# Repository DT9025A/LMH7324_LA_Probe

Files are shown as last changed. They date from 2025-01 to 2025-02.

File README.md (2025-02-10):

# LMH7324_LA_Probe

使用 KiCad 进行设计的，基于 LMH7324 的 RIGOL PLA2216 逻分探头替代，在 DHO924S 上、62.5MHz 输入频率下实测可用。



# 复刻指导

1. 请依据开源工程 [MSO5000/DHO900 逻辑探头](https://oshwhub.com/zoomf1/pla2216) 中的 "转接板新版本" 打样出转接板，并购买连接器；
2. 依据本工程中的 Gerber 文件打样出探头板，请勿直接使用立创 EDA 进行导出，以免出现意外的错误（即使打 1.6mm 板厚也可以大力出奇迹焊上 1.27mm 的 IDC 连接器）；
3. 购买元器件，LMH7324 在立创商城上约 80RMB / 片；
4. 进行焊接装配。

# 主要 BOM 清单

| 值 | 封装 | 数量 | 
| :---: | :---: | :---: |
| 3.3pF | 0402 | 16 |
| 27pF | 0402 | 16 |
| 100nF | 0402 | 64 |
| 499R | 0402 | 16 |
| 300R | 0402 | 16 |
| 90.9K | 0402 | 16 |
| 10K | 0402 | 16 |
| 49R9 | 4x0603 | 8 |
| 220R | 4x0603 | 8 |
| LMH7324 | WQFN-32-1EP_5x5mm_P0.5mm_EP3.1x3.1mm | 4 |

# Test pictures

校准截图：

校准截图

62.5MHz 方波输入测试：



50MHz 正弦波输入测试：

50MHz正弦波输入测试

# References

- 感谢开源工程 [MSO5000/DHO900 逻辑探头](https://oshwhub.com/zoomf1/pla2216)
- 感谢 [EEVBlog](https://www.eevblog.com/forum/testgear/rpl1116-active-logic-probe-pod-for-1000z-series-teardown/) 中分享资料的各位

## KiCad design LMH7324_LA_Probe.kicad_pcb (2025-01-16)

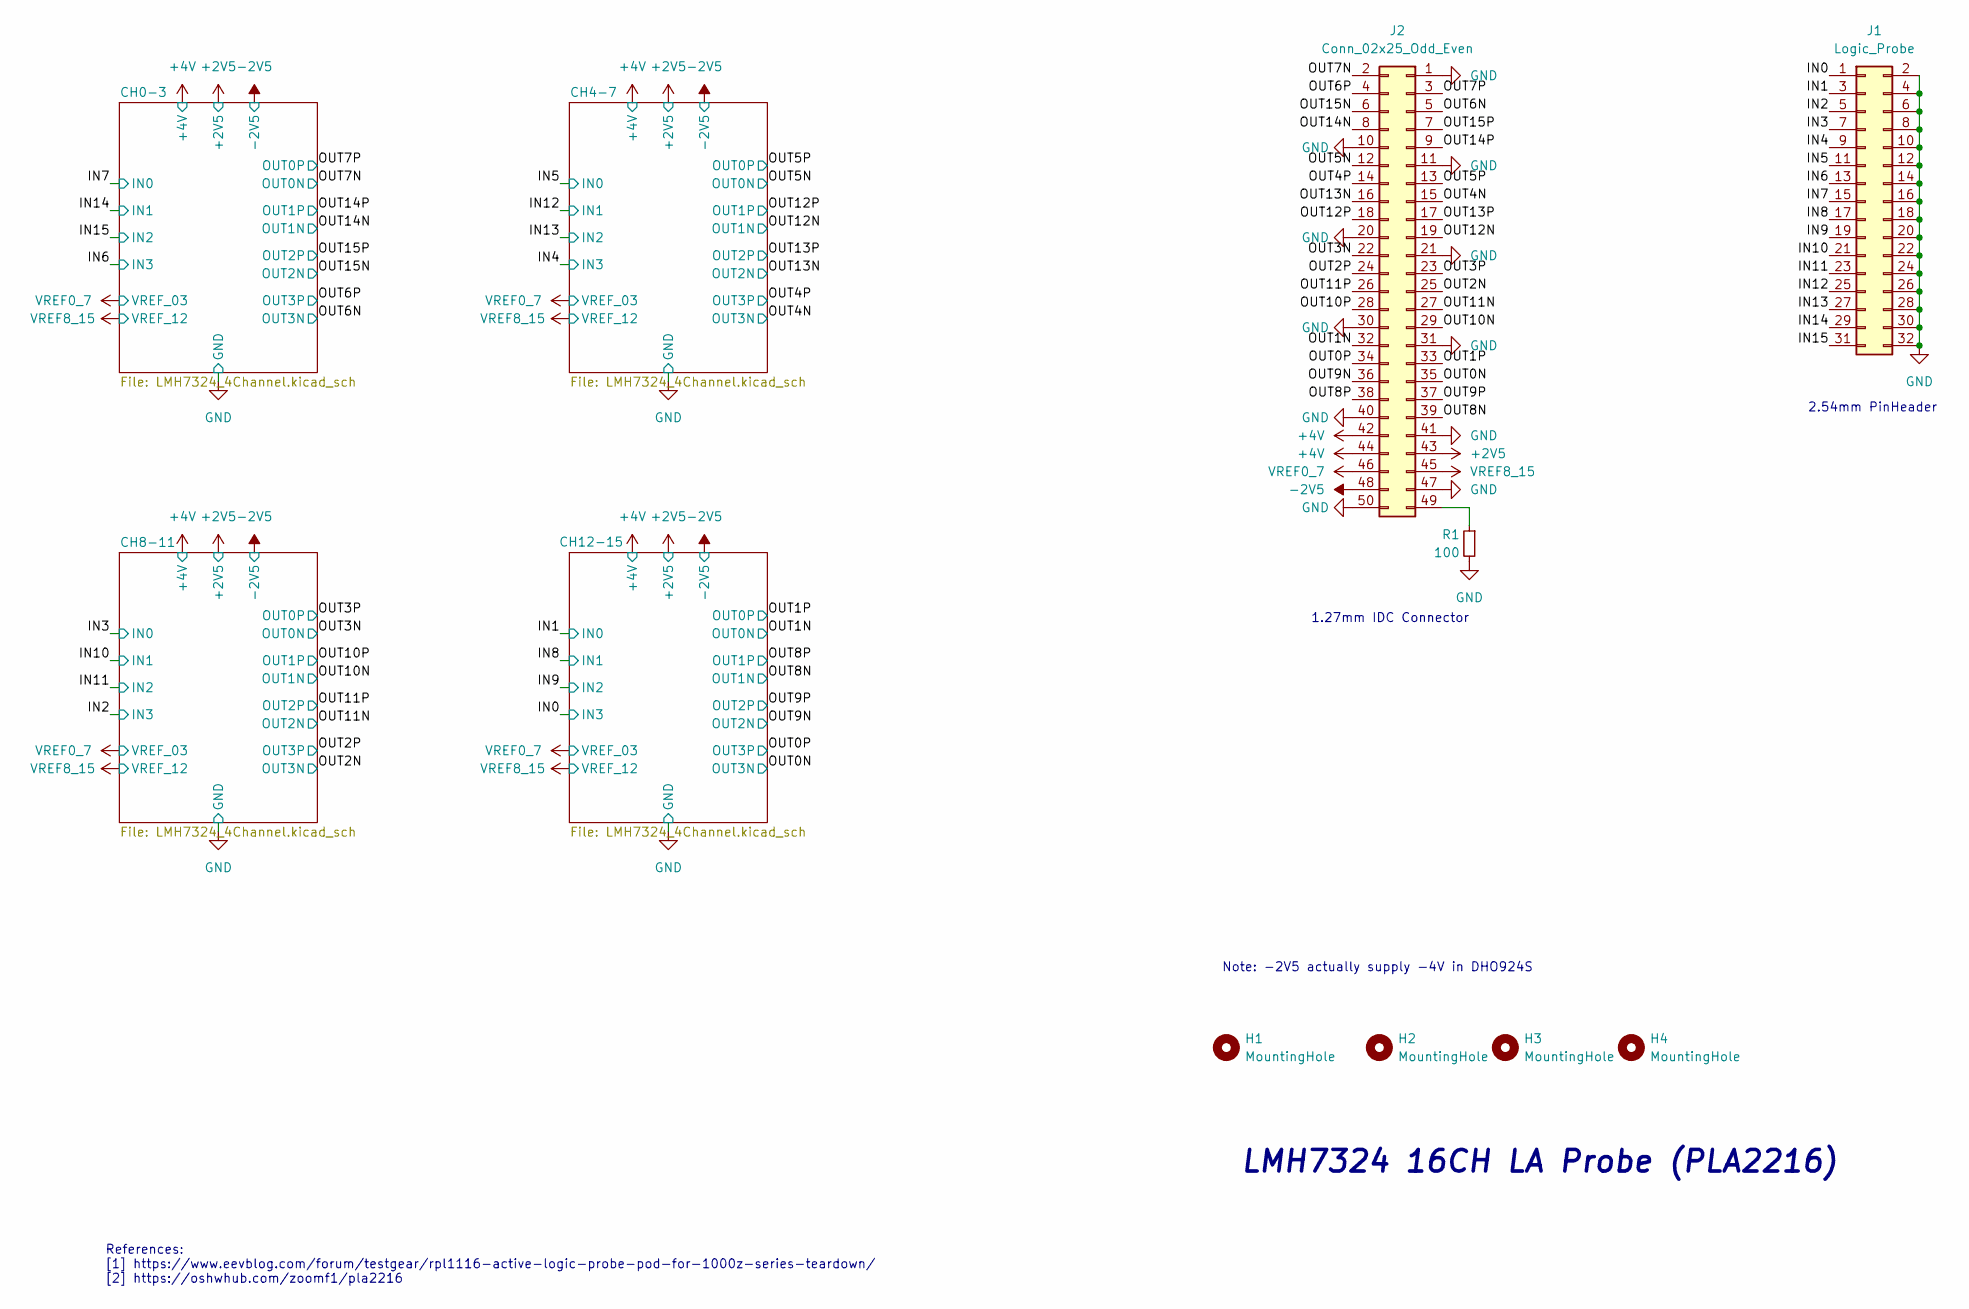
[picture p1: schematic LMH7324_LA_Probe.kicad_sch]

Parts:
H1, H2, H3, H4: MountingHole; MountingHole_2.2mm_M2
J1: Logic_Probe; PinHeader_02x16_2.54mm_SMD
J2: Conn_02x25_Odd_Even; PinHeader_02x25_1.27mm_SMD
R1: 100; R_0603_1608Metric; tolerance 1%; LCSC C17414

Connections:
+2V5: J2.43; also elsewhere on the board
+4V: J2.42, J2.44; also elsewhere on the board
-2V5: J2.48; also elsewhere on the board
/IN0: J1.1; also elsewhere on the board
/IN1: J1.3; also elsewhere on the board
/IN2: J1.5; also elsewhere on the board
/IN3: J1.7; also elsewhere on the board
/IN4: J1.9; also elsewhere on the board
/IN5: J1.11; also elsewhere on the board
/IN6: J1.13; also elsewhere on the board
/IN7: J1.15; also elsewhere on the board
/IN8: J1.17; also elsewhere on the board
/IN9: J1.19; also elsewhere on the board
/IN10: J1.21; also elsewhere on the board
/IN11: J1.23; also elsewhere on the board
/IN12: J1.25; also elsewhere on the board
/IN13: J1.27; also elsewhere on the board
/IN14: J1.29; also elsewhere on the board
/IN15: J1.31; also elsewhere on the board
/OUT0N: J2.35; also elsewhere on the board
/OUT0P: J2.34; also elsewhere on the board
/OUT1N: J2.32; also elsewhere on the board
/OUT1P: J2.33; also elsewhere on the board
/OUT2N: J2.25; also elsewhere on the board
/OUT2P: J2.24; also elsewhere on the board
/OUT3N: J2.22; also elsewhere on the board
/OUT3P: J2.23; also elsewhere on the board
/OUT4N: J2.15; also elsewhere on the board
/OUT4P: J2.14; also elsewhere on the board
/OUT5N: J2.12; also elsewhere on the board
/OUT5P: J2.13; also elsewhere on the board
/OUT6N: J2.5; also elsewhere on the board
/OUT6P: J2.4; also elsewhere on the board
/OUT7N: J2.2; also elsewhere on the board
/OUT7P: J2.3; also elsewhere on the board
/OUT8N: J2.39; also elsewhere on the board
/OUT8P: J2.38; also elsewhere on the board
/OUT9N: J2.36; also elsewhere on the board
/OUT9P: J2.37; also elsewhere on the board
/OUT10N: J2.29; also elsewhere on the board
/OUT10P: J2.28; also elsewhere on the board
/OUT11N: J2.27; also elsewhere on the board
/OUT11P: J2.26; also elsewhere on the board
/OUT12N: J2.19; also elsewhere on the board
/OUT12P: J2.18; also elsewhere on the board
/OUT13N: J2.16; also elsewhere on the board
/OUT13P: J2.17; also elsewhere on the board
/OUT14N: J2.8; also elsewhere on the board
/OUT14P: J2.9; also elsewhere on the board
/OUT15N: J2.6; also elsewhere on the board
/OUT15P: J2.7; also elsewhere on the board
GND: J1.2, J1.4, J1.6, J1.8, J1.10, J1.12, J1.14, J1.16, J1.18, J1.20, J1.22, J1.24, J1.26, J1.28, J1.30, J1.32, J2.1, J2.10, J2.11, J2.20, J2.21, J2.30, J2.31, J2.40, J2.41, J2.47, J2.50, R1.2; also elsewhere on the board
unnamed: J2.49, R1.1
VREF0_7: J2.46; also elsewhere on the board
VREF8_15: J2.45; also elsewhere on the board

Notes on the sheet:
References: [1] https://www.eevblog.com/forum/testgear/rpl1116-active-logic-probe-pod-for-1000z-series-teardown/ [2] https://oshwhub.com/zoomf1/pla2216
2.54mm PinHeader
1.27mm IDC Connector
LMH7324 16CH LA Probe (PLA2216)
Note: -2V5 actually supply -4V in DHO924S

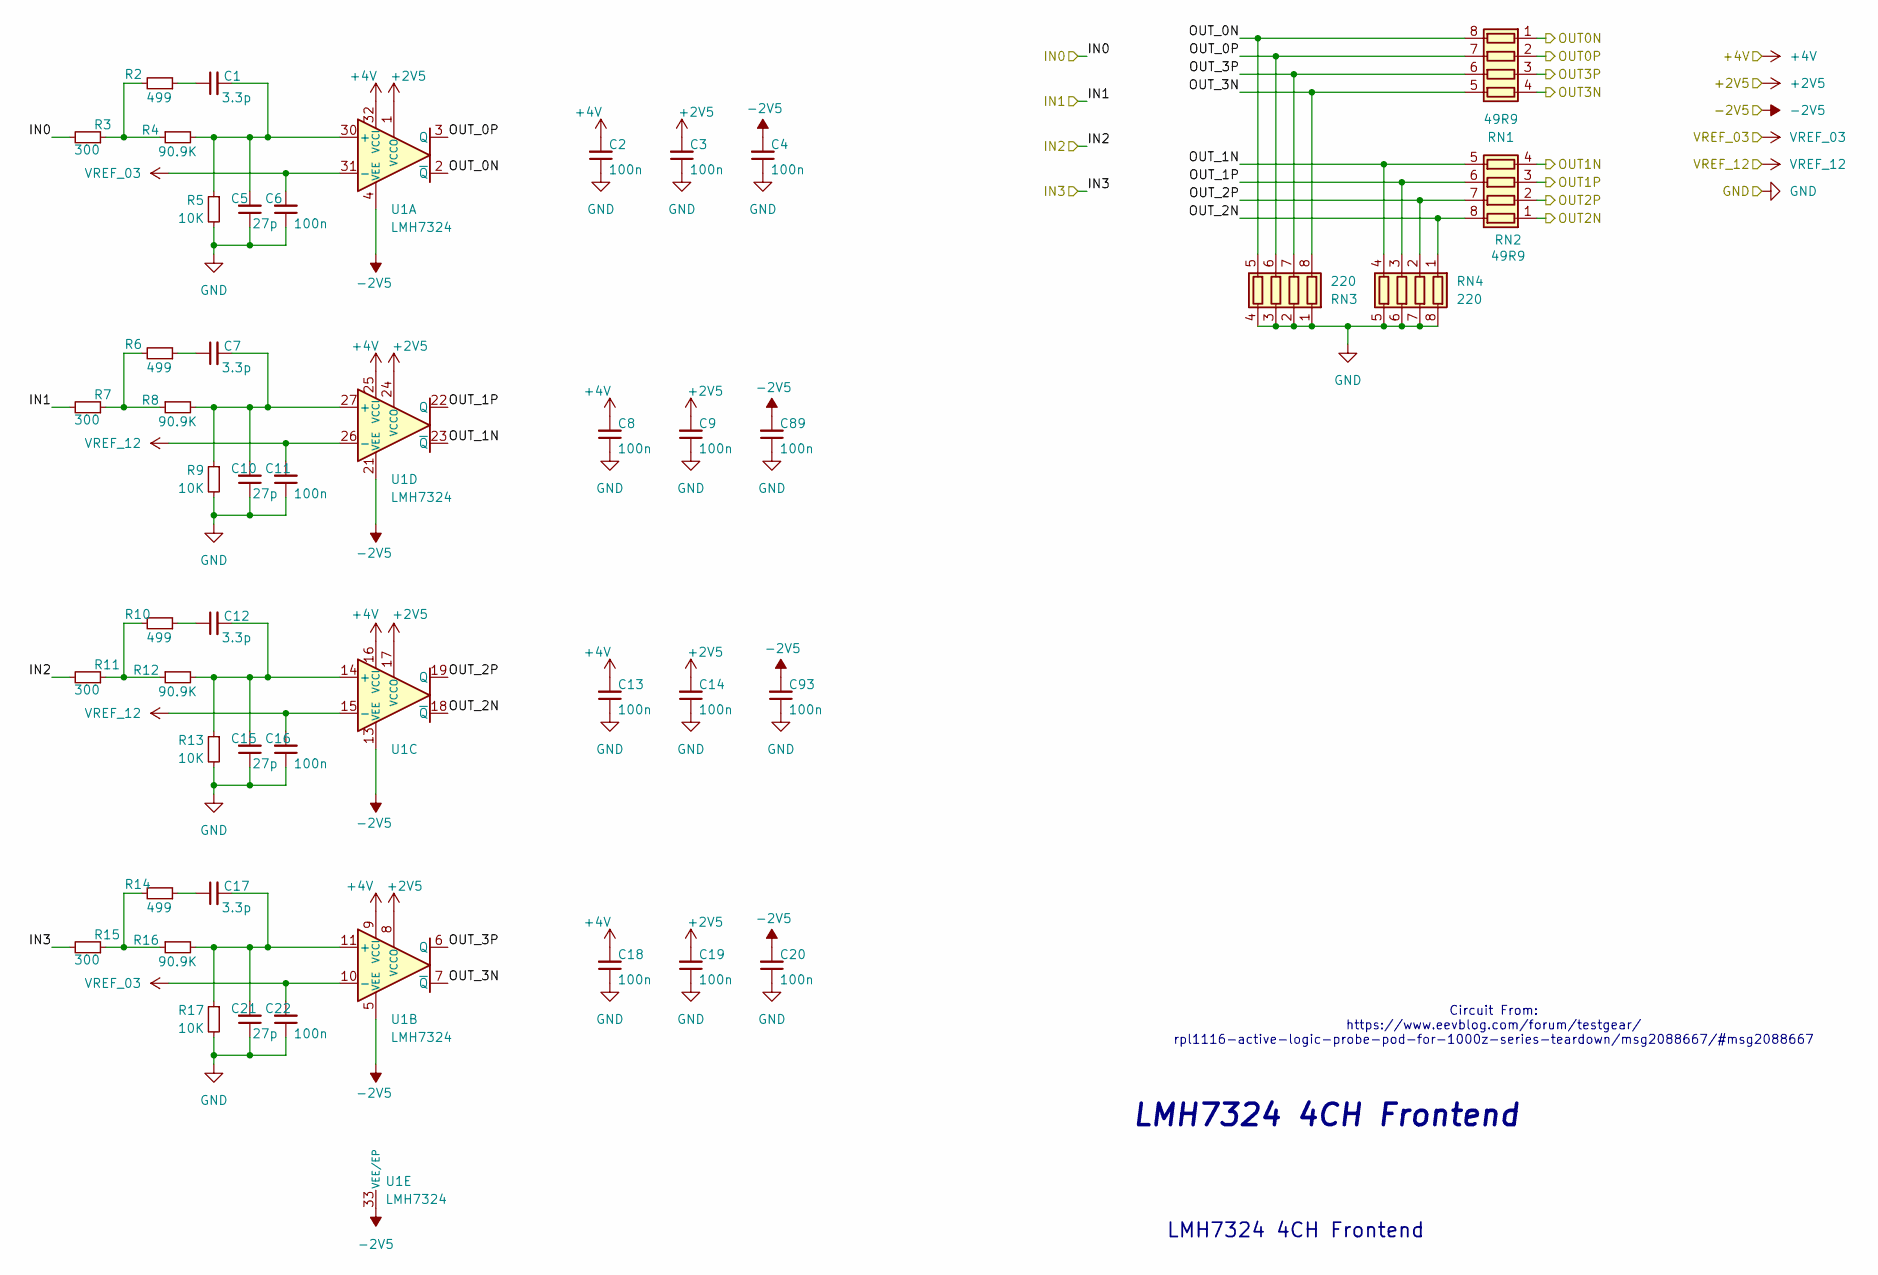
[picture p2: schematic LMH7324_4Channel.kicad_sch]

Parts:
C1, C7, C12, C17: 3.3p; C_0402_1005Metric; tolerance 10%; voltage 50 V; LCSC C1811
C2, C3, C4, C6, C8, C9, C11, C13, C14, C16, C18, C19, C20, C22, C89, C93: 100n; C_0402_1005Metric; tolerance 10%; voltage 50 V; LCSC C49678
C5, C10, C15, C21: 27p; C_0402_1005Metric; tolerance 10%; voltage 50 V; LCSC C1808
R2, R6, R10, R14: 499; R_0402_1005Metric; tolerance 1%; LCSC C17722
R3, R7, R11, R15: 300; R_0402_1005Metric; tolerance 1%; LCSC C17617
R4, R8, R12, R16: 90.9K; R_0402_1005Metric; tolerance 1%; LCSC C17860
R5, R9, R13, R17: 10K; R_0402_1005Metric; tolerance 1%; LCSC C17414
RN1, RN2: 49R9; R_Array_Convex_4x0603
RN3, RN4: 220; R_Array_Convex_4x0603
U1: LMH7324; WQFN-32-1EP_5x5mm_P0.5mm_EP3.1x3.1mm

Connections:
+2V5: C3.2, C9.2, C14.2, C19.2, U1.1 (VCCO), U1.8 (VCCO), U1.17 (VCCO), U1.24 (VCCO); also elsewhere on the board
+4V: C2.2, C8.2, C13.2, C18.2, U1.9 (VCCI), U1.16 (VCCI), U1.25 (VCCI), U1.32 (VCCI); also elsewhere on the board
-2V5: C4.2, C20.2, C89.2, C93.2, U1.4 (VEE), U1.5 (VEE), U1.12 (VEE), U1.13 (VEE), U1.20 (VEE), U1.21 (VEE), U1.28 (VEE), U1.29 (VEE), U1.33 (VEE/EP); also elsewhere on the board
/CH0-3/OUT_0N: RN1.8 (R1.2), RN3.5 (R4.2), U1.2 (~Q)
/CH0-3/OUT_0P: RN1.7 (R2.2), RN3.6 (R3.2), U1.3 (Q)
/CH0-3/OUT_1N: RN2.5 (R4.2), RN4.4 (R4.1), U1.23 (~Q)
/CH0-3/OUT_1P: RN2.6 (R3.2), RN4.3 (R3.1), U1.22 (Q)
/CH0-3/OUT_2N: RN2.8 (R1.2), RN4.1 (R1.1), U1.18 (~Q)
/CH0-3/OUT_2P: RN2.7 (R2.2), RN4.2 (R2.1), U1.19 (Q)
/CH0-3/OUT_3N: RN1.5 (R4.2), RN3.8 (R1.2), U1.7 (~Q)
/CH0-3/OUT_3P: RN1.6 (R3.2), RN3.7 (R2.2), U1.6 (Q)
/IN6: R15.2; also elsewhere on the board
/IN7: R3.2; also elsewhere on the board
/IN14: R7.2; also elsewhere on the board
/IN15: R11.2; also elsewhere on the board
/OUT6N: RN1.4 (R4.1); also elsewhere on the board
/OUT6P: RN1.3 (R3.1); also elsewhere on the board
/OUT7N: RN1.1 (R1.1); also elsewhere on the board
/OUT7P: RN1.2 (R2.1); also elsewhere on the board
/OUT14N: RN2.4 (R4.1); also elsewhere on the board
/OUT14P: RN2.3 (R3.1); also elsewhere on the board
/OUT15N: RN2.1 (R1.1); also elsewhere on the board
/OUT15P: RN2.2 (R2.1); also elsewhere on the board
GND: C2.1, C3.1, C4.1, C5.1, C6.1, C8.1, C9.1, C10.1, C11.1, C13.1, C14.1, C15.1, C16.1, C18.1, C19.1, C20.1, C21.1, C22.1, C89.1, C93.1, R5.2, R9.2, R13.2, R17.2, RN3.1 (R1.1), RN3.2 (R2.1), RN3.3 (R3.1), RN3.4 (R4.1), RN4.5 (R4.2), RN4.6 (R3.2), RN4.7 (R2.2), RN4.8 (R1.2); also elsewhere on the board
unnamed: C1.1, R2.1
unnamed: C7.1, R6.1
unnamed: C12.1, R10.1
unnamed: C17.1, R14.1
unnamed: R2.2, R3.1, R4.1
unnamed: R6.2, R7.1, R8.1
unnamed: R10.2, R11.1, R12.1
unnamed: R14.2, R15.1, R16.1
unnamed: C1.2, C5.2, R4.2, R5.1, U1.30 (+)
unnamed: C17.2, C21.2, R16.2, R17.1, U1.11 (+)
unnamed: C12.2, C15.2, R12.2, R13.1, U1.14 (+)
unnamed: C7.2, C10.2, R8.2, R9.1, U1.27 (+)
VREF0_7: C6.2, C22.2, U1.10 (-), U1.31 (-); also elsewhere on the board
VREF8_15: C11.2, C16.2, U1.15 (-), U1.26 (-); also elsewhere on the board

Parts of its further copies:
C23, C29, C34, C39, C45, C51, C56, C61, C67, C73, C78, C83: 3.3p; C_0402_1005Metric; tolerance 10%; voltage 50 V; LCSC C1811
C24, C25, C26, C28, C30, C31, C33, C35, C36, C38, C40, C41, C42, C44, C46, C47, C48, C50, C52, C53, C55, C57, C58, C60, C62, C63, C64, C66, C68, C69, C70, C72, C74, C75, C77, C79, C80, C82, C84, C85, C86, C88, C90, C91, C92, C94, C95, C96: 100n; C_0402_1005Metric; tolerance 10%; voltage 50 V; LCSC C49678
C27, C32, C37, C43, C49, C54, C59, C65, C71, C76, C81, C87: 27p; C_0402_1005Metric; tolerance 10%; voltage 50 V; LCSC C1808
R18, R22, R26, R30, R34, R38, R42, R46, R50, R54, R58, R62: 499; R_0402_1005Metric; tolerance 1%; LCSC C17722
R19, R23, R27, R31, R35, R39, R43, R47, R51, R55, R59, R63: 300; R_0402_1005Metric; tolerance 1%; LCSC C17617
R20, R24, R28, R32, R36, R40, R44, R48, R52, R56, R60, R64: 90.9K; R_0402_1005Metric; tolerance 1%; LCSC C17860
R21, R25, R29, R33, R37, R41, R45, R49, R53, R57, R61, R65: 10K; R_0402_1005Metric; tolerance 1%; LCSC C17414
RN5, RN6, RN9, RN10, RN13, RN14: 49R9; R_Array_Convex_4x0603
RN7, RN8, RN11, RN12, RN15, RN16: 220; R_Array_Convex_4x0603
U2, U3, U4: LMH7324; WQFN-32-1EP_5x5mm_P0.5mm_EP3.1x3.1mm

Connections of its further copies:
+2V5: C25.2, C31.2, C36.2, C41.2, C47.2, C53.2, C58.2, C63.2, C69.2, C75.2, C80.2, C85.2, U2.1 (VCCO), U2.8 (VCCO), U2.17 (VCCO), U2.24 (VCCO), U3.1 (VCCO), U3.8 (VCCO), U3.17 (VCCO), U3.24 (VCCO), U4.1 (VCCO), U4.8 (VCCO), U4.17 (VCCO), U4.24 (VCCO); also elsewhere on the board
+4V: C24.2, C30.2, C35.2, C40.2, C46.2, C52.2, C57.2, C62.2, C68.2, C74.2, C79.2, C84.2, U2.9 (VCCI), U2.16 (VCCI), U2.25 (VCCI), U2.32 (VCCI), U3.9 (VCCI), U3.16 (VCCI), U3.25 (VCCI), U3.32 (VCCI), U4.9 (VCCI), U4.16 (VCCI), U4.25 (VCCI), U4.32 (VCCI); also elsewhere on the board
-2V5: C26.2, C42.2, C48.2, C64.2, C70.2, C86.2, C90.2, C91.2, C92.2, C94.2, C95.2, C96.2, U2.4 (VEE), U2.5 (VEE), U2.12 (VEE), U2.13 (VEE), U2.20 (VEE), U2.21 (VEE), U2.28 (VEE), U2.29 (VEE), U2.33 (VEE/EP), U3.4 (VEE), U3.5 (VEE), U3.12 (VEE), U3.13 (VEE), U3.20 (VEE), U3.21 (VEE), U3.28 (VEE), U3.29 (VEE), U3.33 (VEE/EP), U4.4 (VEE), U4.5 (VEE), U4.12 (VEE), U4.13 (VEE), U4.20 (VEE), U4.21 (VEE), U4.28 (VEE), U4.29 (VEE), U4.33 (VEE/EP); also elsewhere on the board
/CH4-7/OUT_0N: RN5.8 (R1.2), RN7.5 (R4.2), U2.2 (~Q)
/CH4-7/OUT_0P: RN5.7 (R2.2), RN7.6 (R3.2), U2.3 (Q)
/CH4-7/OUT_1N: RN6.5 (R4.2), RN8.4 (R4.1), U2.23 (~Q)
/CH4-7/OUT_1P: RN6.6 (R3.2), RN8.3 (R3.1), U2.22 (Q)
/CH4-7/OUT_2N: RN6.8 (R1.2), RN8.1 (R1.1), U2.18 (~Q)
/CH4-7/OUT_2P: RN6.7 (R2.2), RN8.2 (R2.1), U2.19 (Q)
/CH4-7/OUT_3N: RN5.5 (R4.2), RN7.8 (R1.2), U2.7 (~Q)
/CH4-7/OUT_3P: RN5.6 (R3.2), RN7.7 (R2.2), U2.6 (Q)
/CH8-11/OUT_0N: RN9.8 (R1.2), RN11.5 (R4.2), U3.2 (~Q)
/CH8-11/OUT_0P: RN9.7 (R2.2), RN11.6 (R3.2), U3.3 (Q)
/CH8-11/OUT_1N: RN10.5 (R4.2), RN12.4 (R4.1), U3.23 (~Q)
/CH8-11/OUT_1P: RN10.6 (R3.2), RN12.3 (R3.1), U3.22 (Q)
/CH8-11/OUT_2N: RN10.8 (R1.2), RN12.1 (R1.1), U3.18 (~Q)
/CH8-11/OUT_2P: RN10.7 (R2.2), RN12.2 (R2.1), U3.19 (Q)
/CH8-11/OUT_3N: RN9.5 (R4.2), RN11.8 (R1.2), U3.7 (~Q)
/CH8-11/OUT_3P: RN9.6 (R3.2), RN11.7 (R2.2), U3.6 (Q)
/CH12-15/OUT_0N: RN13.8 (R1.2), RN15.5 (R4.2), U4.2 (~Q)
/CH12-15/OUT_0P: RN13.7 (R2.2), RN15.6 (R3.2), U4.3 (Q)
/CH12-15/OUT_1N: RN14.5 (R4.2), RN16.4 (R4.1), U4.23 (~Q)
/CH12-15/OUT_1P: RN14.6 (R3.2), RN16.3 (R3.1), U4.22 (Q)
/CH12-15/OUT_2N: RN14.8 (R1.2), RN16.1 (R1.1), U4.18 (~Q)
/CH12-15/OUT_2P: RN14.7 (R2.2), RN16.2 (R2.1), U4.19 (Q)
/CH12-15/OUT_3N: RN13.5 (R4.2), RN15.8 (R1.2), U4.7 (~Q)
/CH12-15/OUT_3P: RN13.6 (R3.2), RN15.7 (R2.2), U4.6 (Q)
/IN0: R63.2; also elsewhere on the board
/IN1: R51.2; also elsewhere on the board
/IN2: R47.2; also elsewhere on the board
/IN3: R35.2; also elsewhere on the board
/IN4: R31.2; also elsewhere on the board
/IN5: R19.2; also elsewhere on the board
/IN8: R55.2; also elsewhere on the board
/IN9: R59.2; also elsewhere on the board
/IN10: R39.2; also elsewhere on the board
/IN11: R43.2; also elsewhere on the board
/IN12: R23.2; also elsewhere on the board
/IN13: R27.2; also elsewhere on the board
/OUT0N: RN13.4 (R4.1); also elsewhere on the board
/OUT0P: RN13.3 (R3.1); also elsewhere on the board
/OUT1N: RN13.1 (R1.1); also elsewhere on the board
/OUT1P: RN13.2 (R2.1); also elsewhere on the board
/OUT2N: RN9.4 (R4.1); also elsewhere on the board
/OUT2P: RN9.3 (R3.1); also elsewhere on the board
/OUT3N: RN9.1 (R1.1); also elsewhere on the board
/OUT3P: RN9.2 (R2.1); also elsewhere on the board
/OUT4N: RN5.4 (R4.1); also elsewhere on the board
/OUT4P: RN5.3 (R3.1); also elsewhere on the board
/OUT5N: RN5.1 (R1.1); also elsewhere on the board
/OUT5P: RN5.2 (R2.1); also elsewhere on the board
/OUT8N: RN14.4 (R4.1); also elsewhere on the board
/OUT8P: RN14.3 (R3.1); also elsewhere on the board
/OUT9N: RN14.1 (R1.1); also elsewhere on the board
/OUT9P: RN14.2 (R2.1); also elsewhere on the board
/OUT10N: RN10.4 (R4.1); also elsewhere on the board
/OUT10P: RN10.3 (R3.1); also elsewhere on the board
/OUT11N: RN10.1 (R1.1); also elsewhere on the board
/OUT11P: RN10.2 (R2.1); also elsewhere on the board
/OUT12N: RN6.4 (R4.1); also elsewhere on the board
/OUT12P: RN6.3 (R3.1); also elsewhere on the board
/OUT13N: RN6.1 (R1.1); also elsewhere on the board
/OUT13P: RN6.2 (R2.1); also elsewhere on the board
GND: C24.1, C25.1, C26.1, C27.1, C28.1, C30.1, C31.1, C32.1, C33.1, C35.1, C36.1, C37.1, C38.1, C40.1, C41.1, C42.1, C43.1, C44.1, C46.1, C47.1, C48.1, C49.1, C50.1, C52.1, C53.1, C54.1, C55.1, C57.1, C58.1, C59.1, C60.1, C62.1, C63.1, C64.1, C65.1, C66.1, C68.1, C69.1, C70.1, C71.1, C72.1, C74.1, C75.1, C76.1, C77.1, C79.1, C80.1, C81.1, C82.1, C84.1, C85.1, C86.1, C87.1, C88.1, C90.1, C91.1, C92.1, C94.1, C95.1, C96.1, R21.2, R25.2, R29.2, R33.2, R37.2, R41.2, R45.2, R49.2, R53.2, R57.2, R61.2, R65.2, RN7.1 (R1.1), RN7.2 (R2.1), RN7.3 (R3.1), RN7.4 (R4.1), RN8.5 (R4.2), RN8.6 (R3.2), RN8.7 (R2.2), RN8.8 (R1.2), RN11.1 (R1.1), RN11.2 (R2.1), RN11.3 (R3.1), RN11.4 (R4.1), RN12.5 (R4.2), RN12.6 (R3.2), RN12.7 (R2.2), RN12.8 (R1.2), RN15.1 (R1.1), RN15.2 (R2.1), RN15.3 (R3.1), RN15.4 (R4.1), RN16.5 (R4.2), RN16.6 (R3.2), RN16.7 (R2.2), RN16.8 (R1.2); also elsewhere on the board
unnamed: C23.1, R18.1
unnamed: C29.1, R22.1
unnamed: C34.1, R26.1
unnamed: C39.1, R30.1
unnamed: C45.1, R34.1
unnamed: C51.1, R38.1
unnamed: C56.1, R42.1
unnamed: C61.1, R46.1
unnamed: C67.1, R50.1
unnamed: C73.1, R54.1
unnamed: C78.1, R58.1
unnamed: C83.1, R62.1
unnamed: R18.2, R19.1, R20.1
unnamed: R22.2, R23.1, R24.1
unnamed: R26.2, R27.1, R28.1
unnamed: R30.2, R31.1, R32.1
unnamed: R34.2, R35.1, R36.1
unnamed: R38.2, R39.1, R40.1
unnamed: R42.2, R43.1, R44.1
unnamed: R46.2, R47.1, R48.1
unnamed: R50.2, R51.1, R52.1
unnamed: R54.2, R55.1, R56.1
unnamed: R58.2, R59.1, R60.1
unnamed: R62.2, R63.1, R64.1
unnamed: C23.2, C27.2, R20.2, R21.1, U2.30 (+)
unnamed: C39.2, C43.2, R32.2, R33.1, U2.11 (+)
unnamed: C34.2, C37.2, R28.2, R29.1, U2.14 (+)
unnamed: C29.2, C32.2, R24.2, R25.1, U2.27 (+)
unnamed: C45.2, C49.2, R36.2, R37.1, U3.30 (+)
unnamed: C61.2, C65.2, R48.2, R49.1, U3.11 (+)
unnamed: C56.2, C59.2, R44.2, R45.1, U3.14 (+)
unnamed: C51.2, C54.2, R40.2, R41.1, U3.27 (+)
unnamed: C67.2, C71.2, R52.2, R53.1, U4.30 (+)
unnamed: C83.2, C87.2, R64.2, R65.1, U4.11 (+)
unnamed: C78.2, C81.2, R60.2, R61.1, U4.14 (+)
unnamed: C73.2, C76.2, R56.2, R57.1, U4.27 (+)
VREF0_7: C28.2, C44.2, C50.2, C66.2, C72.2, C88.2, U2.10 (-), U2.31 (-), U3.10 (-), U3.31 (-), U4.10 (-), U4.31 (-); also elsewhere on the board
VREF8_15: C33.2, C38.2, C55.2, C60.2, C77.2, C82.2, U2.15 (-), U2.26 (-), U3.15 (-), U3.26 (-), U4.15 (-), U4.26 (-); also elsewhere on the board

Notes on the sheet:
LMH7324 4CH Frontend
Circuit From: https://www.eevblog.com/forum/testgear/ rpl1116-active-logic-probe-pod-for-1000z-series-teardown/msg2088667/#msg2088667

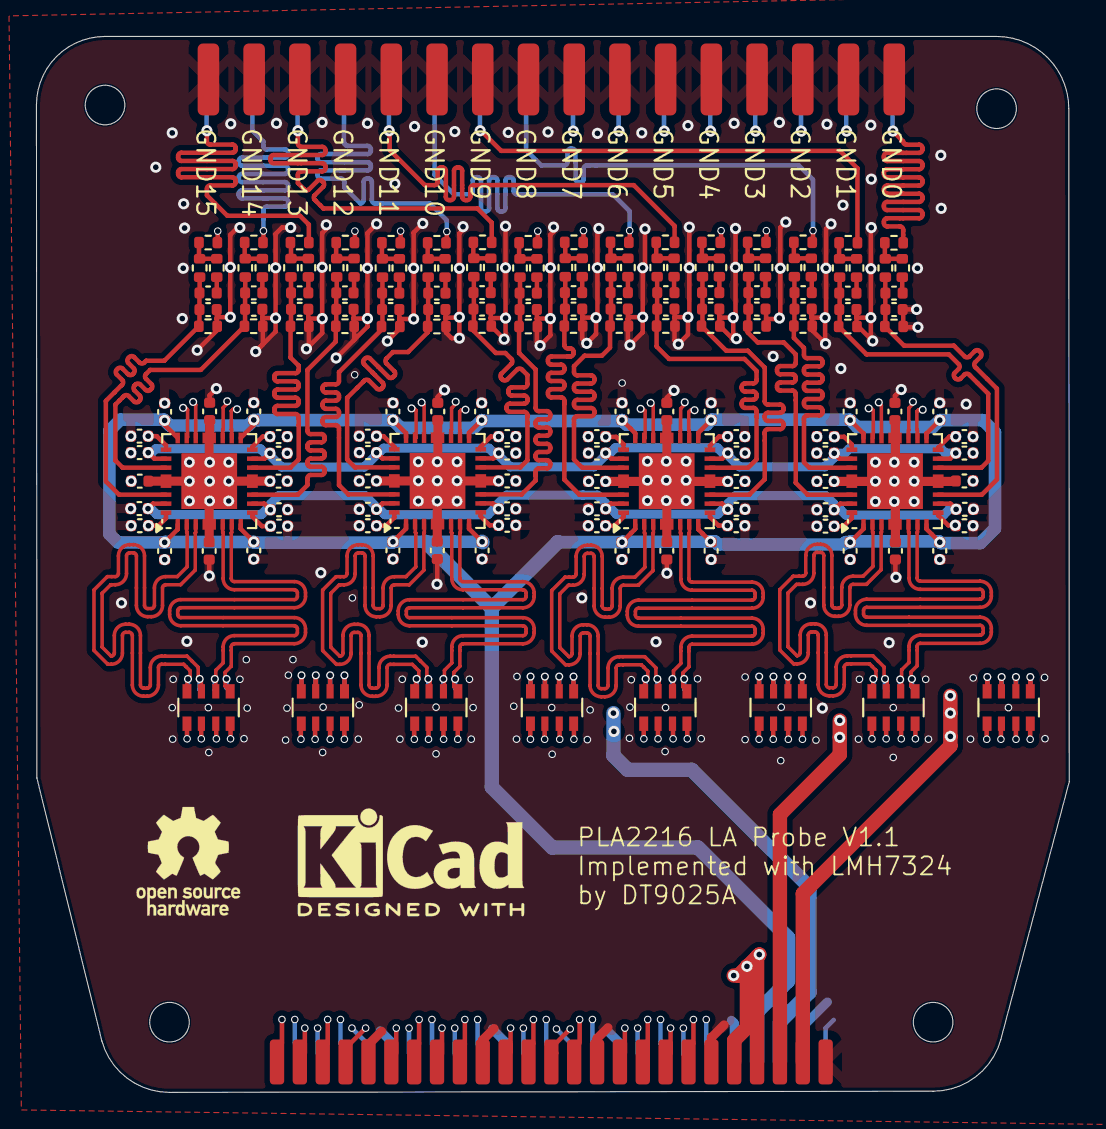
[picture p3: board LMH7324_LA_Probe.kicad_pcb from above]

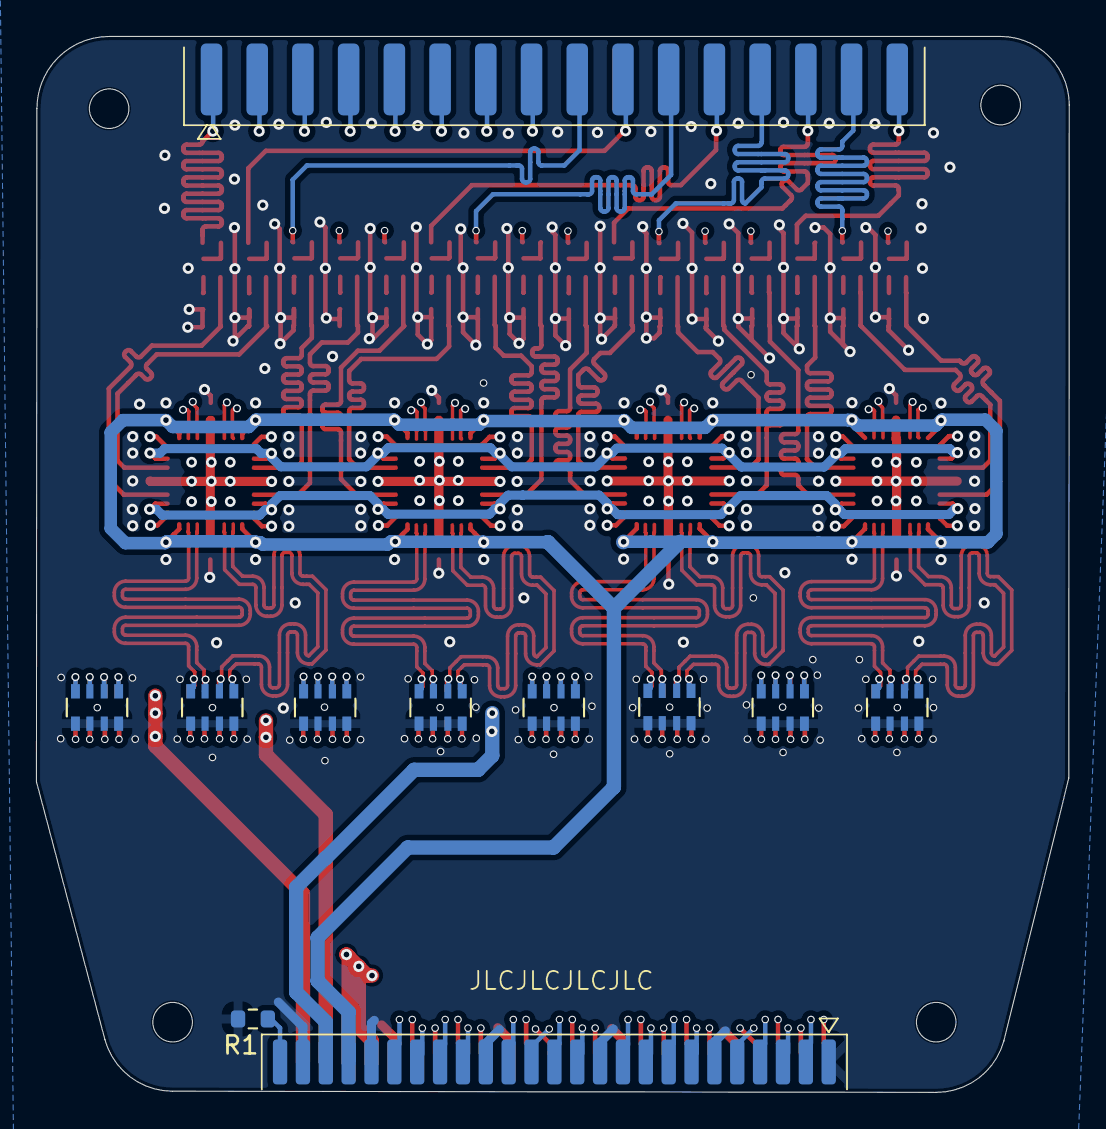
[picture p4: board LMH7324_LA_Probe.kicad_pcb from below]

Board: 6 copper layers, 57.4 x 58.7 mm, 187 parts (11 on the bottom side), 135 nets.
